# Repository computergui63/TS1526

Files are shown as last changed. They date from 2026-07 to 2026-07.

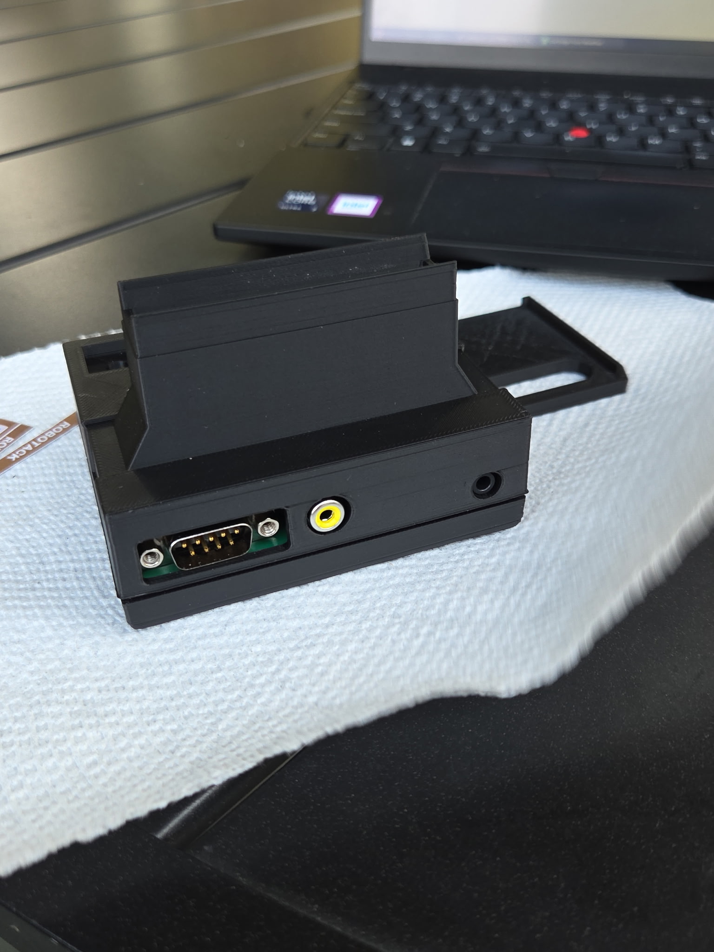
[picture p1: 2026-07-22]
Images/1526-4.jpg

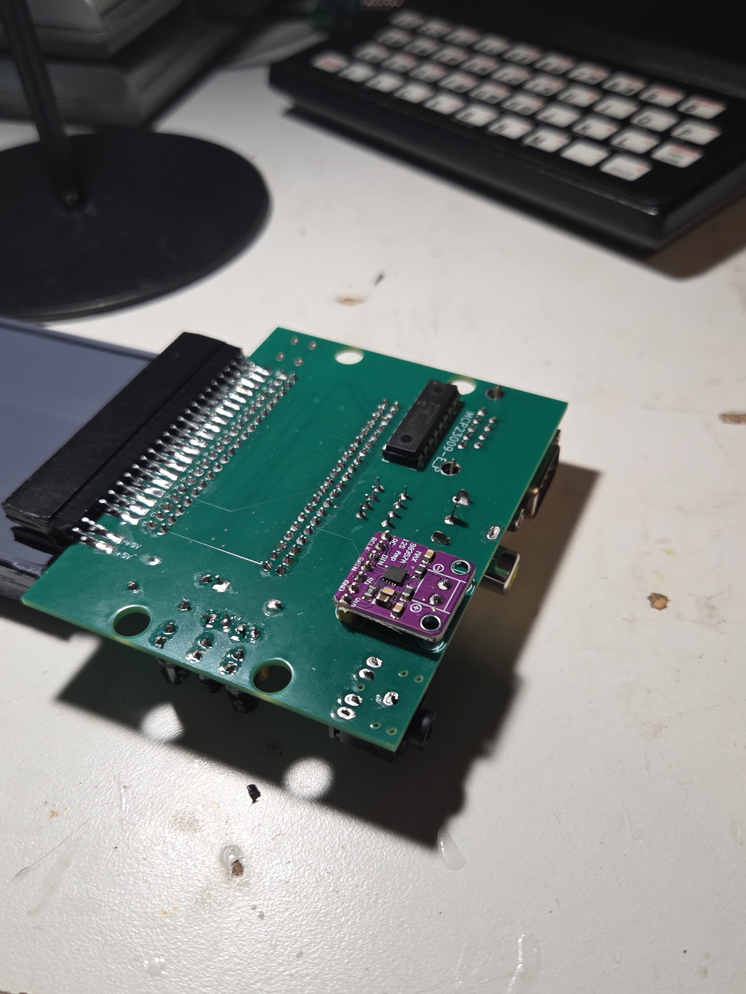
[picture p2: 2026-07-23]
Images/1526-6.jpg

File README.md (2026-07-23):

# TS1526
This is an open source derivative of the amazing OpenSpand project, designed to fit in a Timex Sinclair 1510 Case.

I've modified the design of the OpenSpand hardware specifically to fit in a Timex Sinclair 1510 modified case.  Some of the modifications includes the removal of the I2C IO and serial IO connections.  I've also replaced the UDA1334 with a MAX98357 chip.  This allows for a speaker to be included in the case powered by an amplifier.  I've also included a 3.5mm Phillips mono port to connect a mono speaker.   I've also eliminated the config button.  Config options are still available via the command options.  To better replicate the 1510, the SD card has moved to the "cartridge" and a cartridge port is provided.  The SD card slot was replaced with a microSD card.

This project is also open source as required via the GPL license.  You are free to modify my hardware as long as it's published as open source.

The Openspand project is published here: https://codeberg.org/NollKollTroll/OpenSpand

All software, manuals and binaries are available there.








HandmadeLogo2

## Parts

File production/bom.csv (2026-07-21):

Designator | Footprint | Quantity | Value | LCSC Part #
C1 | CP_Radial_D5.0mm_P2.50mm | 1 | 16V 47uF
C2 | CP_Radial_D5.0mm_P2.50mm | 1 | 10V 1uF
C3, C5 | C_Disc_D3.0mm_W1.6mm_P2.50mm | 2 | 100nF
C4 | CP_Radial_D5.0mm_P2.50mm | 1 | 10uF
D1 | D_DO-41_SOD81_P10.16mm_Horizontal | 1 | 1N5817
J1 | EDGE ZX81 BOTTOM | 1 | Connector ZX81
J2 | DSUB-9_Male_Horizontal_P2.77x2.84mm_EdgePinOffset4.94mm_Housed_MountingHolesOffset7.48mm | 1 | Joystick Connector
J3 | ZX Video1 | 1 | Video Connector
J4 | adafruit-MAX98357 | 1 | Audio Connector
J5 | EDGE ZX81 90_copy | 1 | Cartridge Slot
J6 | PJ-307 | 1 | AudioJack3
R1 | R_Axial_DIN0207_L6.3mm_D2.5mm_P10.16mm_Horizontal | 1 | 270R
R2 | R_Axial_DIN0207_L6.3mm_D2.5mm_P10.16mm_Horizontal | 1 | 470R
R3 | R_Axial_DIN0207_L6.3mm_D2.5mm_P10.16mm_Horizontal | 1 | 100KOhm
SW1 | SW_PUSH_6mm_H5mm | 1 | SW_Push
U1 | P2350Pico2XL | 1 | Pico 2 XL
U2 | M | 1 | MCP23009-E_P | mcp23009-E/p

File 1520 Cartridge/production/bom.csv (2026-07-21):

Designator | Footprint | Quantity | Value | LCSC Part #
CARTRIDGE FRONT | EDGE ZX81 Cartridge | 1 | ZX 81 Cartridge Slot
J3 | CUI_MSD-1-A | 1 | MSD-1-A

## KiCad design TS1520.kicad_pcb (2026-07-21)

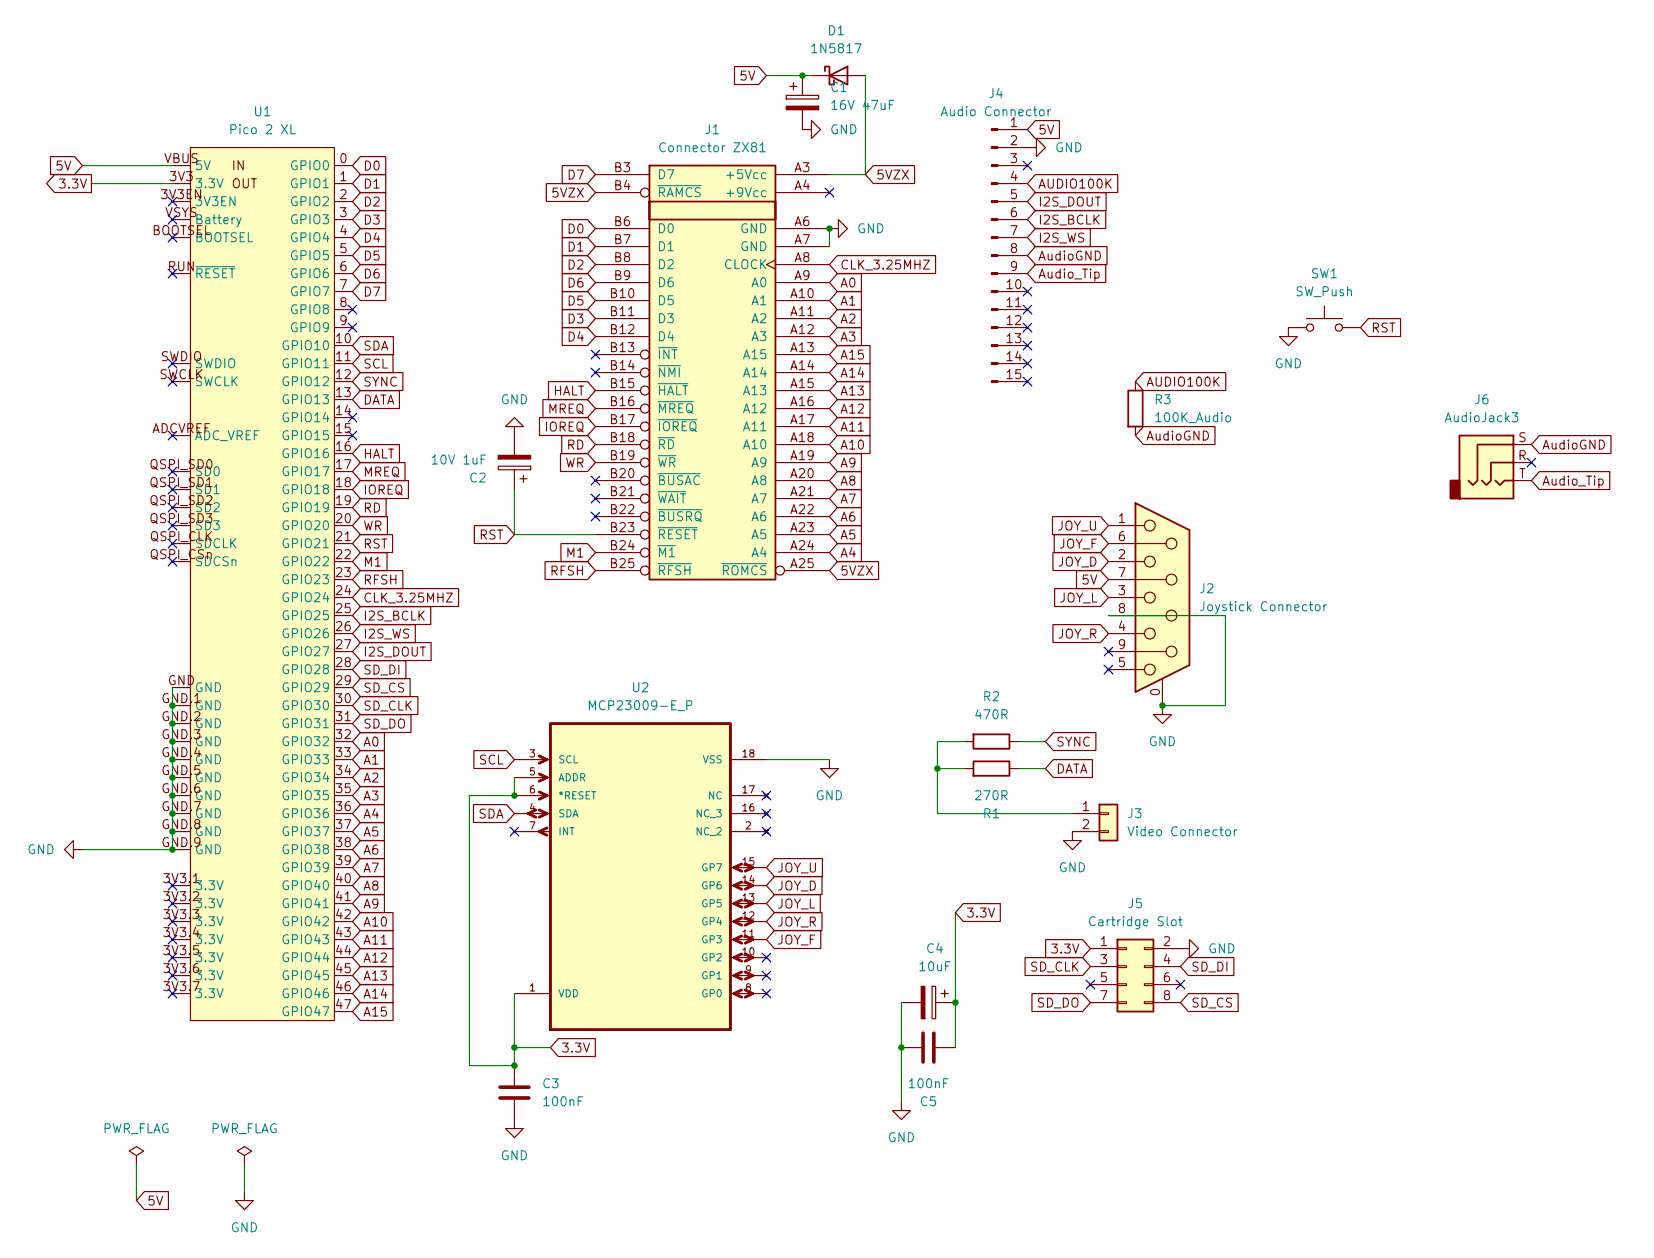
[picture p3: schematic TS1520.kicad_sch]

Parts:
C1: 16V 47uF; CP_Radial_D5.0mm_P2.50mm
C2: 10V 1uF; CP_Radial_D5.0mm_P2.50mm
C3, C5: 100nF; C_Disc_D3.0mm_W1.6mm_P2.50mm
C4: 10uF; CP_Radial_D5.0mm_P2.50mm
D1: 1N5817; D_DO-41_SOD81_P10.16mm_Horizontal
J1: Connector ZX81; EDGE ZX81 BOTTOM
J2: Joystick Connector; DSUB-9_Male_Horizontal_P2.77x2.84mm_EdgePinOffset4.94mm_Hou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
J3: Video Connector; ZX Video1
J4: Audio Connector; adafruit-MAX98357
J5: Cartridge Slot; EDGE ZX81 90_copy
J6: AudioJack3; PJ-307
R1: 270R; R_Axial_DIN0207_L6.3mm_D2.5mm_P10.16mm_Horizontal
R2: 470R; R_Axial_DIN0207_L6.3mm_D2.5mm_P10.16mm_Horizontal
R3: 100K_Audio; R_Axial_DIN0207_L6.3mm_D2.5mm_P10.16mm_Horizontal
SW1: SW_Push; SW_PUSH_6mm_H5mm
U1: Pico 2 XL; P2350Pico2XL
U2: MCP23009-E_P; M; MPN mcp23009-E/p; DigiKey_Part_Number MCP23009-E/P-ND

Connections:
3.3V: C3.1, C4.1, C5.2, J5.1, U1.3V3 (3.3V), U2.1 (VDD), U2.5 (ADDR), U2.6 (*RESET)
5V: C1.1, D1.1 (K), J2.7, J4.1, U1.VBUS (5V)
5VZX: D1.2 (A), J1.A3 (+5Vcc), J1.A25 (~ROMCS), J1.B4 (~RAMCS)
A0: J1.A9 (A0), U1.32 (GPIO32)
A1: J1.A10 (A1), U1.33 (GPIO33)
A2: J1.A11 (A2), U1.34 (GPIO34)
A3: J1.A12 (A3), U1.35 (GPIO35)
A4: J1.A24 (A4), U1.36 (GPIO36)
A5: J1.A23 (A5), U1.37 (GPIO37)
A6: J1.A22 (A6), U1.38 (GPIO38)
A7: J1.A21 (A7), U1.39 (GPIO39)
A8: J1.A20 (A8), U1.40 (GPIO40)
A9: J1.A19 (A9), U1.41 (GPIO41)
A10: J1.A18 (A10), U1.42 (GPIO42)
A11: J1.A17 (A11), U1.43 (GPIO43)
A12: J1.A16 (A12), U1.44 (GPIO44)
A13: J1.A15 (A13), U1.45 (GPIO45)
A14: J1.A14, U1.46 (GPIO46)
A15: J1.A13 (A15), U1.47 (GPIO47)
AUDIO100K: J4.4, R3.1
AudioGND: J4.8, J6.S, R3.2
Audio_Tip: J4.9, J6.T
CLK_3.25MHZ: J1.A8 (CLOCK), U1.24 (GPIO24)
D0: J1.B6 (D0), U1.0 (GPIO0)
D1: J1.B7 (D1), U1.1 (GPIO1)
D2: J1.B8 (D2), U1.2 (GPIO2)
D3: J1.B11 (D3), U1.3 (GPIO3)
D4: J1.B12 (D4), U1.4 (GPIO4)
D5: J1.B10 (D5), U1.5 (GPIO5)
D6: J1.B9 (D6), U1.6 (GPIO6)
D7: J1.B3 (D7), U1.7 (GPIO7)
DATA: R1.1, U1.13 (GPIO13)
GND: C1.2, C2.2, C3.2, C4.2, C5.1, J1.A6 (GND), J1.A7 (GND), J2.0 (PAD), J2.8, J3.2, J4.2, J5.2, SW1.1, U1.GND, U1.GND.1 (GND), U1.GND.2 (GND), U1.GND.3 (GND), U1.GND.4 (GND), U1.GND.5 (GND), U1.GND.6 (GND), U1.GND.7 (GND), U1.GND.8 (GND), U1.GND.9 (GND), U2.18 (VSS)
HALT: J1.B15 (~HALT), U1.16 (GPIO16)
I2S_BCLK: J4.6, U1.25 (GPIO25)
I2S_DOUT: J4.5, U1.27 (GPIO27)
I2S_WS: J4.7, U1.26 (GPIO26)
IOREQ: J1.B17 (~IOREQ), U1.18 (GPIO18)
JOY_D: J2.2, U2.14 (GP6)
JOY_F: J2.6, U2.11 (GP3)
JOY_L: J2.3, U2.13 (GP5)
JOY_R: J2.4, U2.12 (GP4)
JOY_U: J2.1, U2.15 (GP7)
M1: J1.B24 (~M1), U1.22 (GPIO22)
MREQ: J1.B16 (~MREQ), U1.17 (GPIO17)
unnamed: J3.1, R1.2, R2.2
RD: J1.B18 (~RD), U1.19 (GPIO19)
RFSH: J1.B25 (~RFSH), U1.23 (GPIO23)
RST: C2.1, J1.B23 (~RESET), SW1.2, U1.21 (GPIO21)
SCL: U1.11 (GPIO11), U2.3 (SCL)
SDA: U1.10 (GPIO10), U2.4 (SDA)
SD_CLK: J5.3, U1.30 (GPIO30)
SD_CS: J5.8, U1.29 (GPIO29)
SD_DI: J5.4, U1.28 (GPIO28)
SD_DO: J5.7, U1.31 (GPIO31)
SYNC: R2.1, U1.12 (GPIO12)
WR: J1.B19 (~WR), U1.20 (GPIO20)

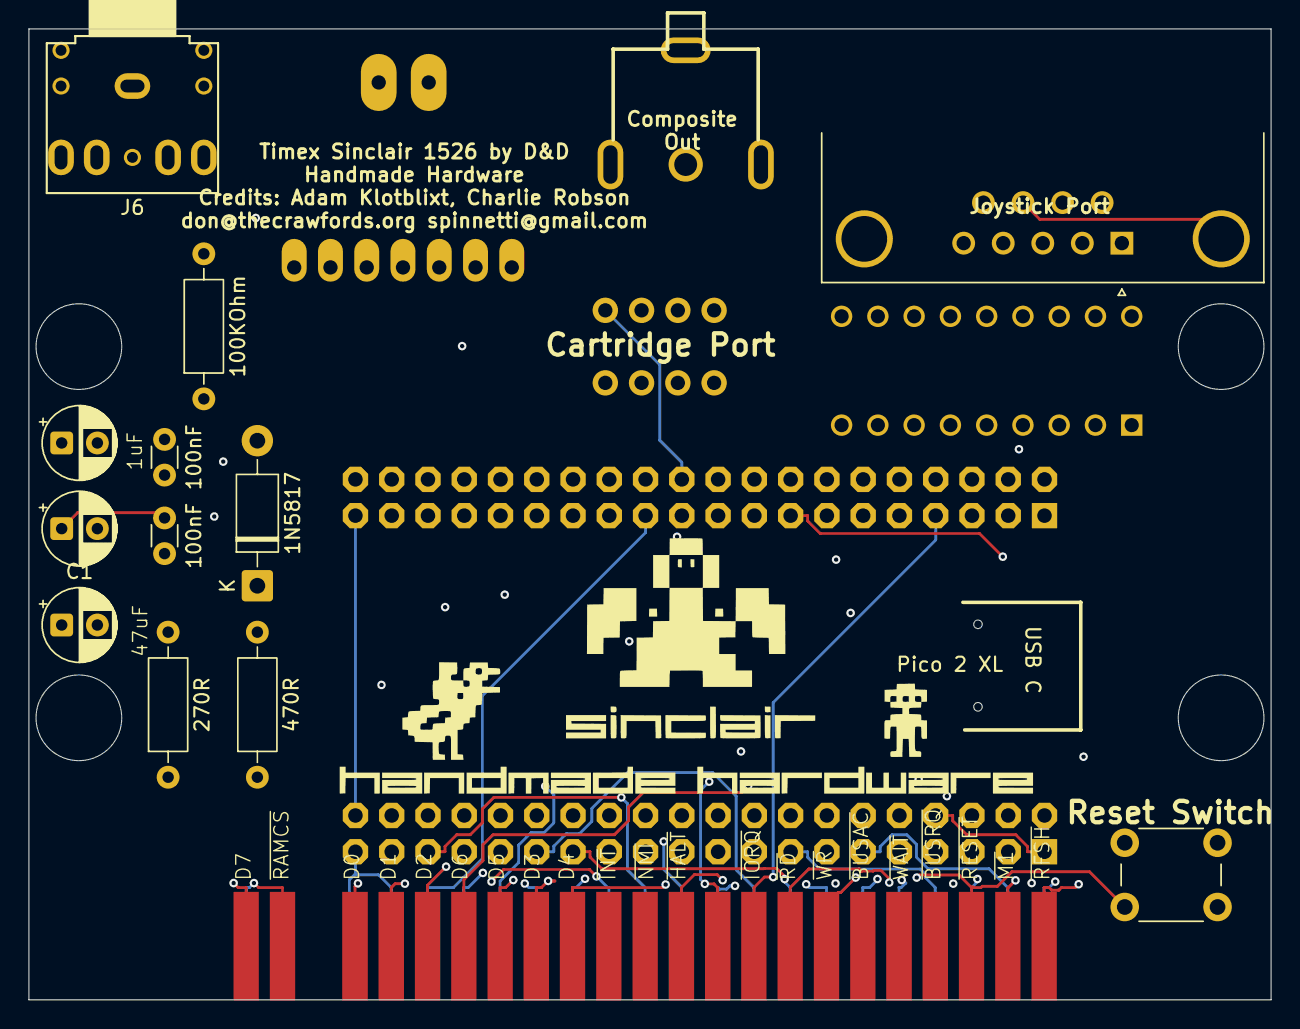
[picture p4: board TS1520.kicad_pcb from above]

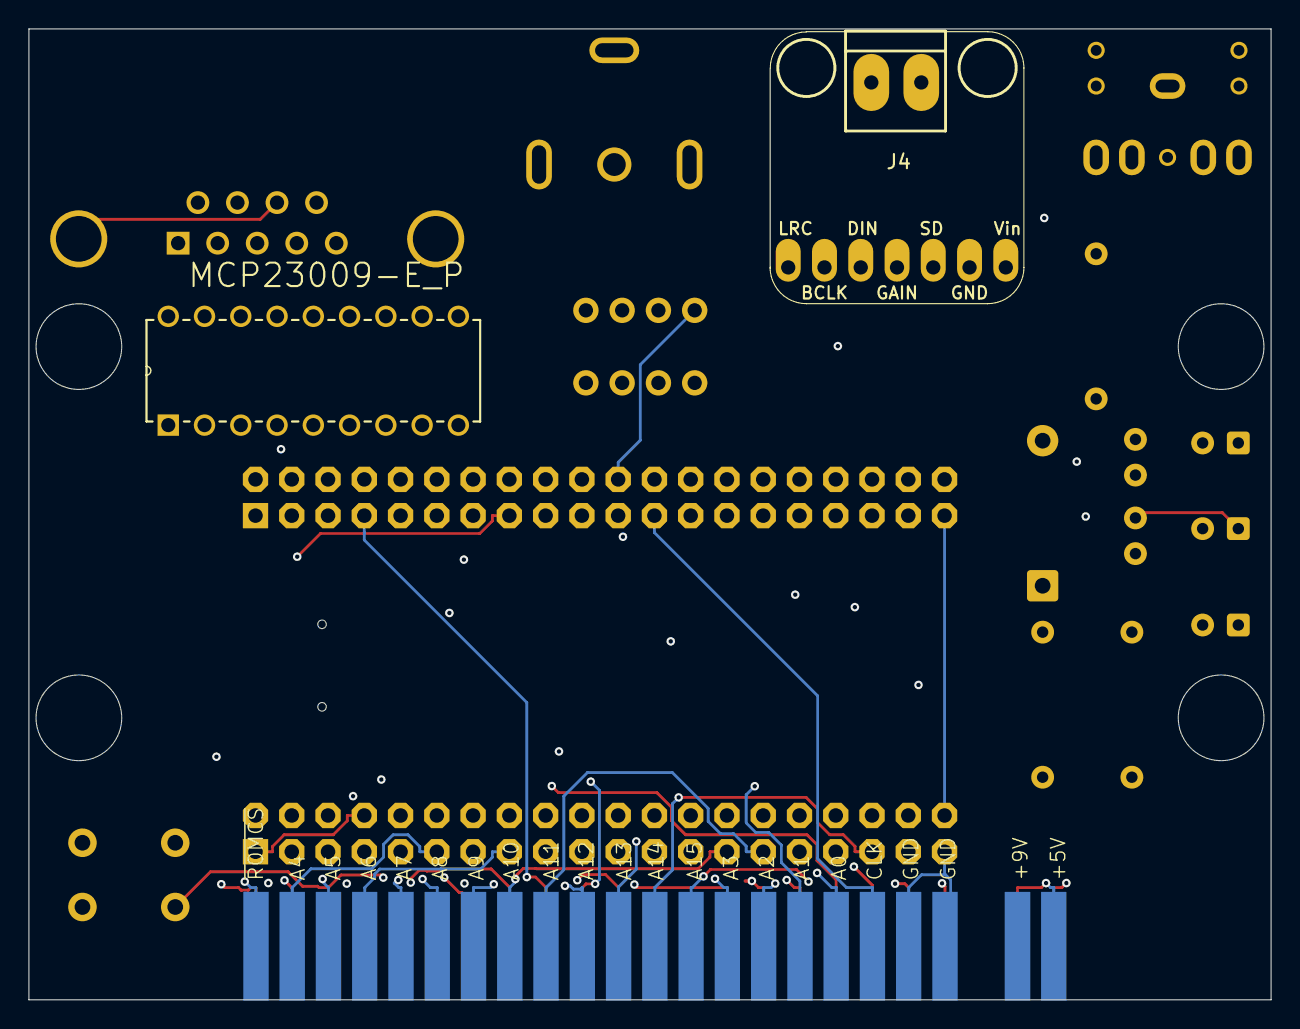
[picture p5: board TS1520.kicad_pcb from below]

Board: 4 copper layers, 87.0 x 68.0 mm, 18 parts (2 on the bottom side), 57 nets.
